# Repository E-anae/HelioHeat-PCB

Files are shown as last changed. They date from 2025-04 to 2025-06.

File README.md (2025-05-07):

# Projet ELEC - PCB

## Architecture

Cette section présente l'architecture d'un thermomètre autonome fonctionnant à
l'aide d'un panneau solaire. L'objectif est de mesurer la température d'un lieu
et d'afficher sur des afficheurs 7 segments tout en assurant une alimentation
énergétique durable à l'aide d'une batterie rechargeable.

### Composants principaux

Les composants que nous utiliserons sont les suivants :

| Référence | Composant | Quantité | Remarques |
| --- | --- | --- | ---- |
| ATTINY85 | Microcontrôleur | 1 | Gestion des capteurs et de l'affichage |
| MCP9700AT-E/LT | Capteur de température | 1 | Mesure de la température |
| 157119S12801 | Afficheur 7 segments | 3 | Affiche numérique de la température |
| PET Solar panel | Mini panneau solaire | 1 | Recharge la batterie |
| CD4511 | Décodeur BCD vers 7 segments | 3 | Simplifie le pilottage de l'afficheur |
| | Batterie rechargeable | 1 | Alimentation autonome |
| 74HC595 | Registre à décalage | 2 | Sérialisation des données |

### Schéma fonctionnel

1. Le panneau solaire charge la batterie via un circuit de gestion de charge.
2. La batterie alimente le microcontrôleur et les afficheurs 7 segments.
3. Le microcontrôleur lit la température via le capteur et affiche les valeurs
sur les afficheurs 7 segments.

Le schéma fonctionnel est présent dans le document `documents/schema.pdf`.

Ce projet permettra de développer une solution autonome et durable pour la
mesure de la température. La conception d'une carte PCB optimisera l'intégration
des composants et la gestion énergétique.

## Fonction de transfert du capteur de température

La fonction de transfert du capteur de température est explicitée dans la partie
4 (*Applications information*) de la fiche de donnée du capteur de température
(`documents/thermal_sensor_datasheet.pdf`).

Cette dernière nous informe que

$$
V_{OUT} = T_C \times T_A + V_{0°C}
$$

avec $V_{OUT}$ la tension de sortie du capteur, $T_C$ le coefficient de
température, $T_A$ la température ambiante et $V_{0°C}$ la tension de sortie du
capteur à 0°C.

On a alors,

$$
\begin{align*}
    V_{OUT} &= T_C \times T_A + V_{0°C} \\
    V_{OUT} - V_{0°C} &= T_C \times T_A \\
    T_A &= \frac{V_{OUT} - V_{0°C}}{T_C}
\end{align*}
$$

avec $V_{0°C} = 500 V$ et $T_C = 10.0 V$.

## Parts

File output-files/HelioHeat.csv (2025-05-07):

Reference | Value | Footprint | Datasheet | Qty | DNP | Exclude from BOM | Exclude from Board
D1,D2,D3 | WL-T7DS_0.39INCH_COMMON-ANODE | WL-T7DS_0.39INCH_COMMON-ANODE:WL-T7DS_0.39INCH |  | 3
J1 | USB_B_Micro | Connector_USB:USB_Micro-B_Amphenol_10103594-0001LF_Horizontal | ~ | 1
R1,R2,R3 | 220 | Resistor_SMD:R_0201_0603Metric | ~ | 3
U1 | ATtiny85-20P | Package_DIP:DIP-8_W7.62mm | http://ww1.microchip.com/downloads/en/DeviceDoc/atmel-2586-avr-8-bit-microcontroller-attiny25-attiny45-attiny85_datasheet.pdf | 1
U2,U3,U4 | CD4511BE | CD4511BE:DIP794W45P254L1969H508Q16 |  | 3
U5,U6 | 74HC595 | 74HC595:SO16 | http://www.ti.com/lit/ds/symlink/sn74hc595.pdf | 2
U7 | MCP9700Ax-ELT | Package_TO_SOT_SMD:SOT-353_SC-70-5 | http://ww1.microchip.com/downloads/en/DeviceDoc/20001942G.pdf | 1

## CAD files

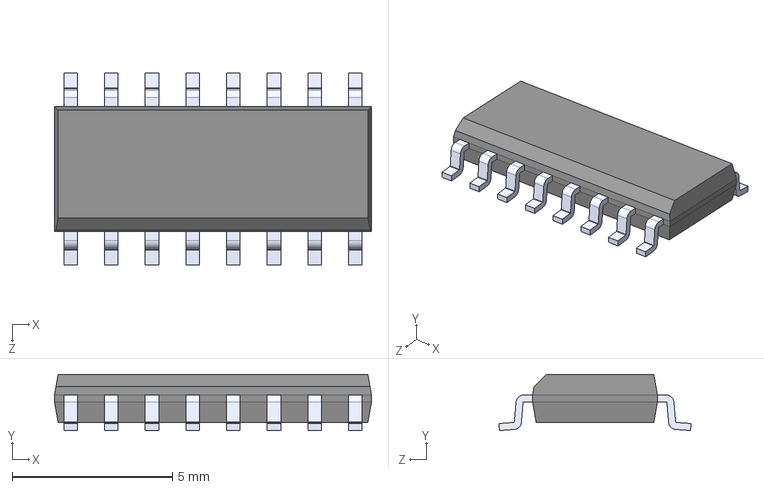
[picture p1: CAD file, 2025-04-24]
HelioHeatPartsLib/74HC595/74HC595.step
9.90 x 1.75 x 6.00 mm

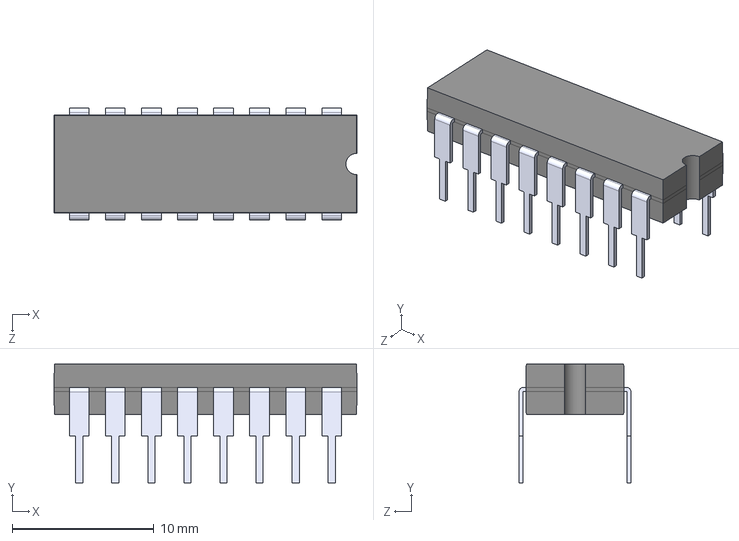
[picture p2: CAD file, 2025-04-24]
HelioHeatPartsLib/CD4511/CD4511BE.step
21.3 x 8.38 x 7.90 mm

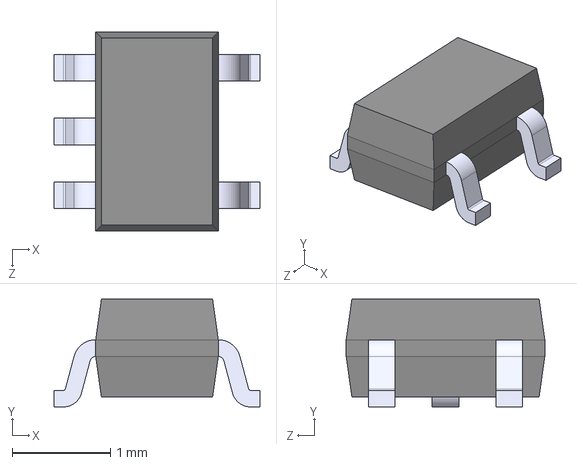
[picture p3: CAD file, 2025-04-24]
HelioHeatPartsLib/MCP9700AT-E_LT.step
2.10 x 1.10 x 2.02 mm

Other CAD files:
HelioHeatPartsLib/WL-T7DS 7 Segments Display THT Single Digit/WL-T7DS_0.39INCH_COMMON-ANODE.step

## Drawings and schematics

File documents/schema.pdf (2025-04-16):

A

1 | 2 | 3 | 4 | 5 | 6

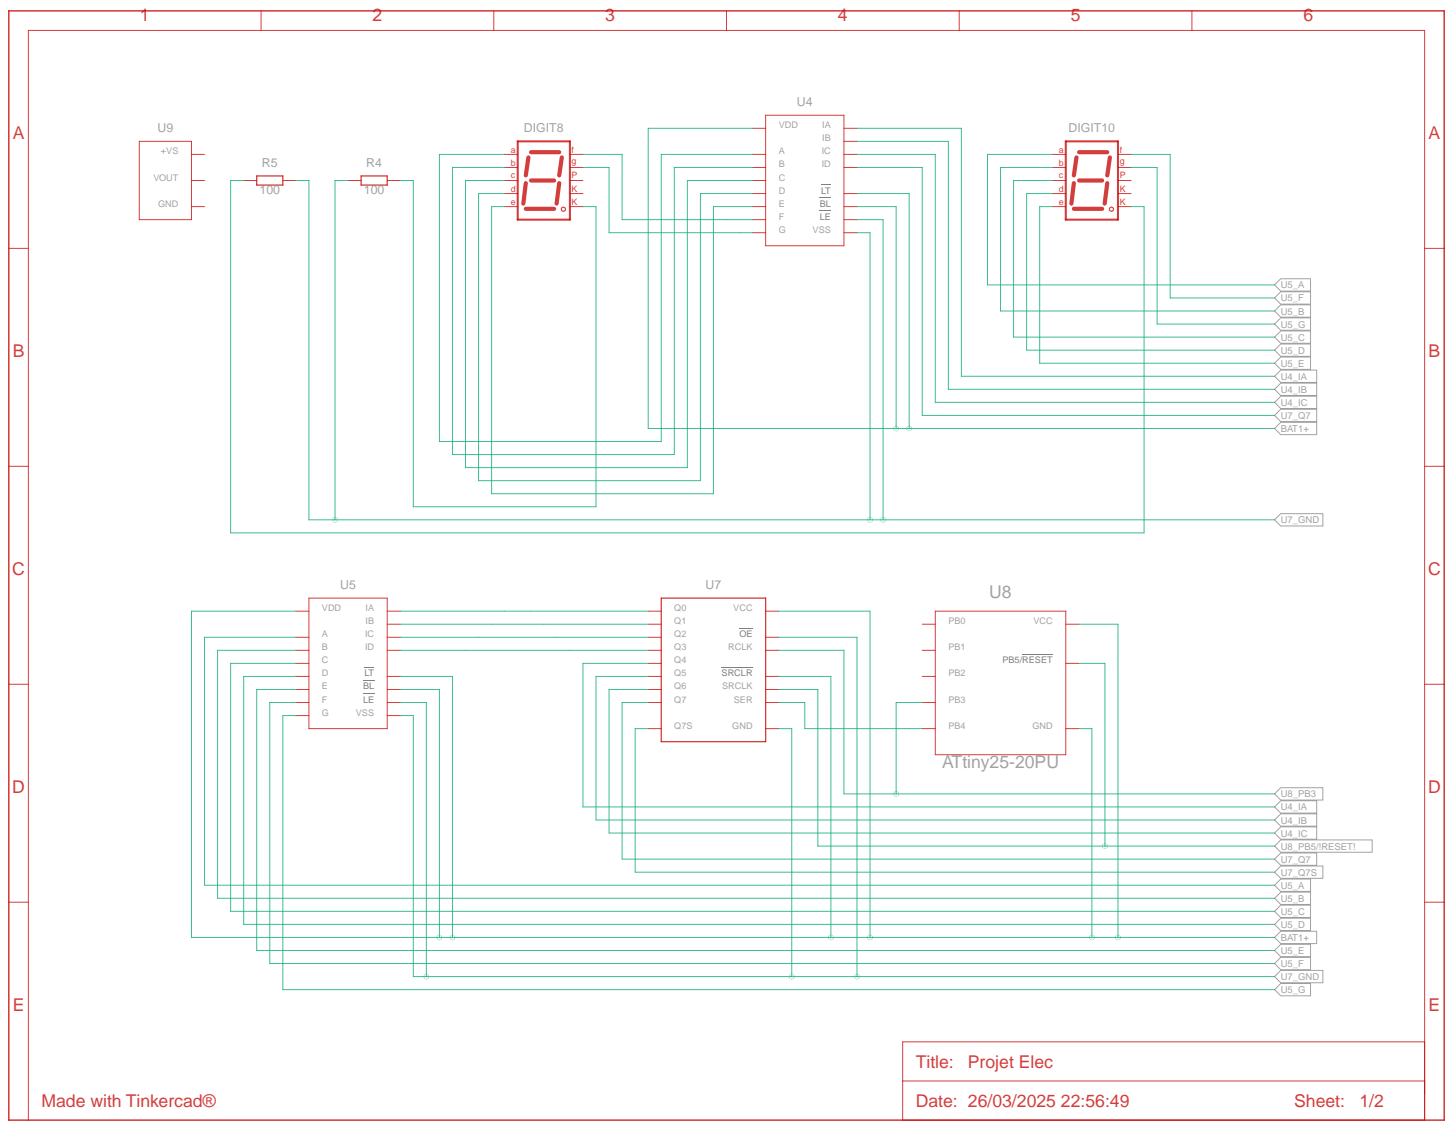
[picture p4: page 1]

A

1 | 2 | 3 | 4 | 5 | 6

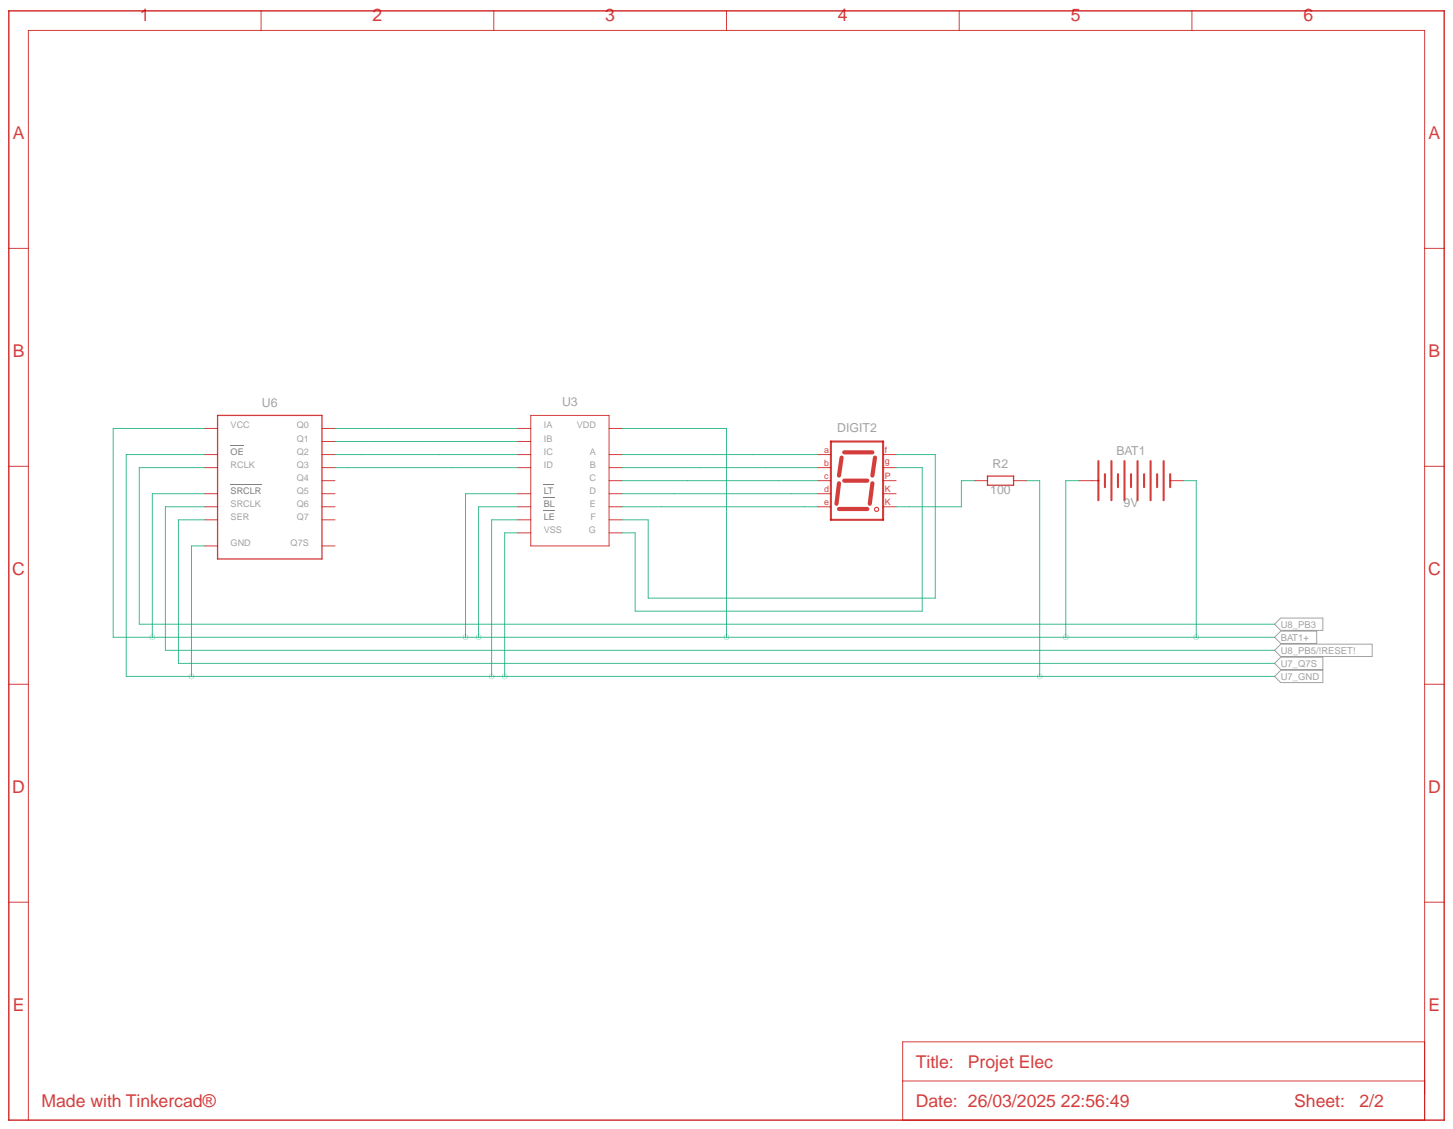
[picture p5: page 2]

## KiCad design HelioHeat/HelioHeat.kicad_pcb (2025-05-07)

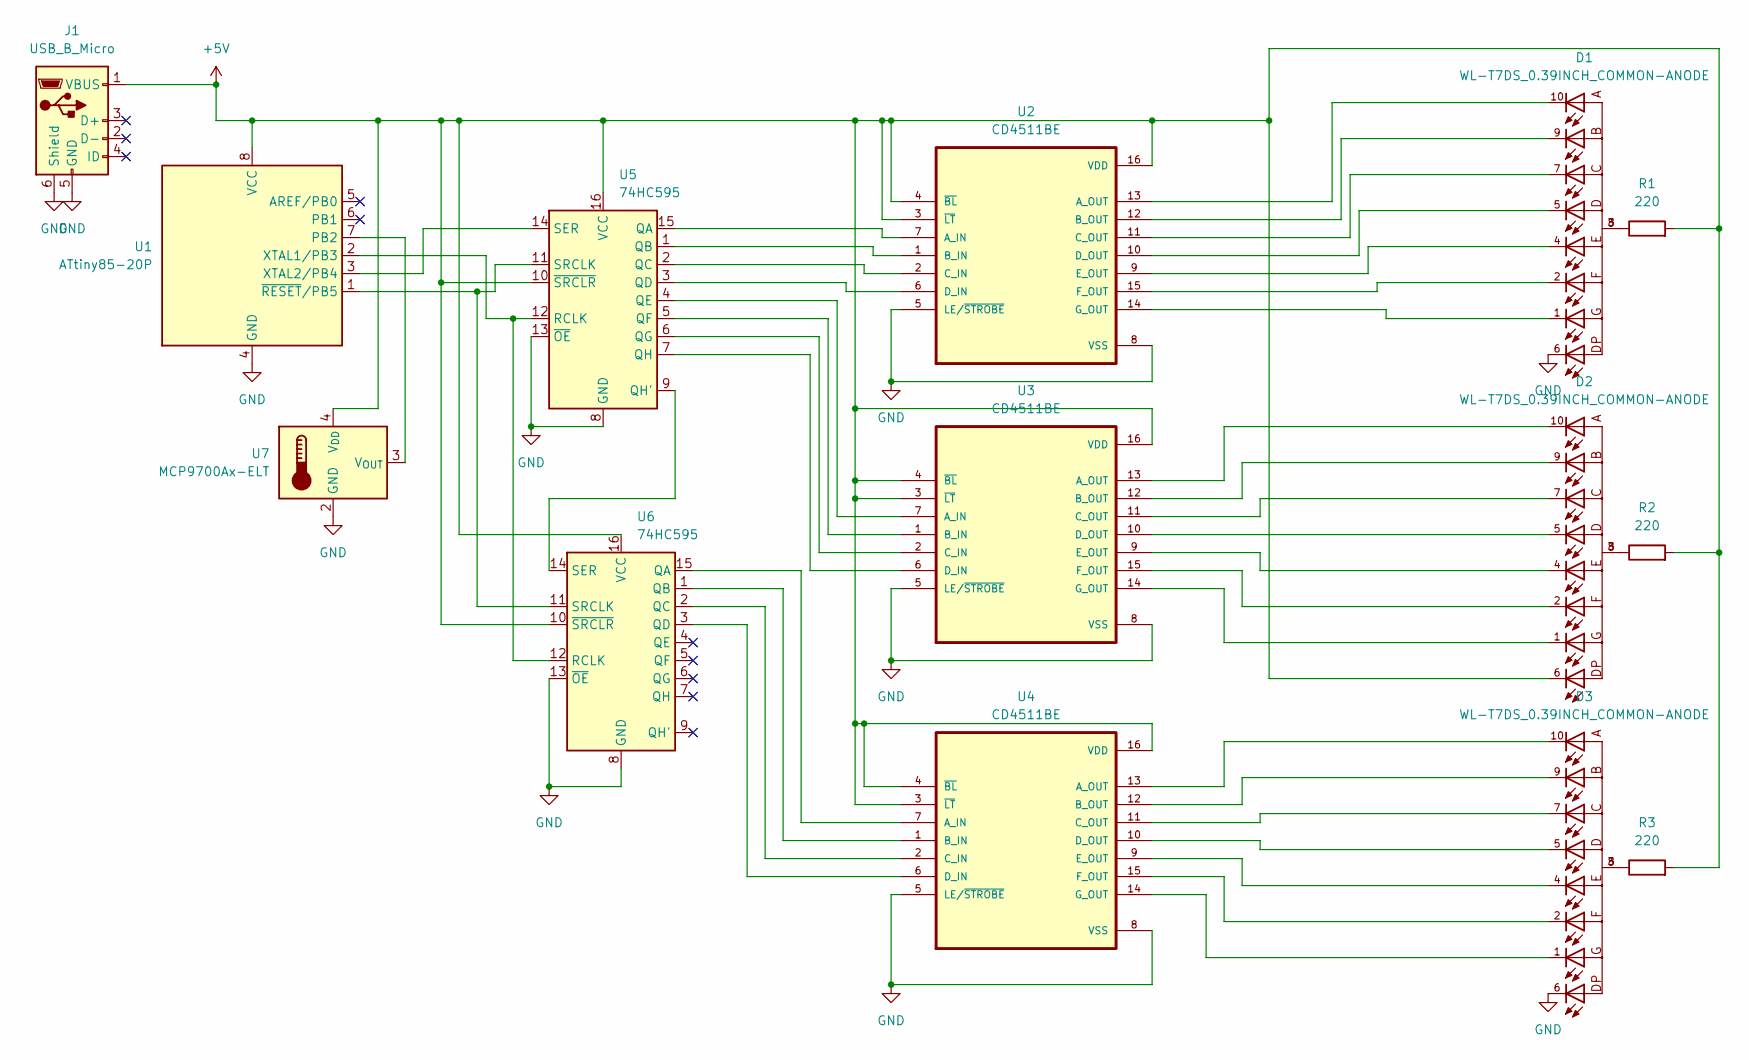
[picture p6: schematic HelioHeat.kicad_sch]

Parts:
D1, D2, D3: WL-T7DS_0.39INCH_COMMON-ANODE; WL-T7DS_0.39INCH
J1: USB_B_Micro; USB_Micro-B_Amphenol_10103594-0001LF_Horizontal
R1, R2, R3: 220; R_0201_0603Metric
U1: ATtiny85-20P; DIP-8_W7.62mm
U2, U3, U4: CD4511BE; DIP794W45P254L1969H508Q16
U5, U6: 74HC595; SO16
U7: MCP9700Ax-ELT; SOT-353_SC-70-5

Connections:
+5V: D2.6, J1.1 (VBUS), R1.2, R2.2, R3.2, U1.8 (VCC), U2.3 (~LT), U2.4 (~BL), U2.16 (VDD), U3.3 (~LT), U3.4 (~BL), U3.16 (VDD), U4.3 (~LT), U4.4 (~BL), U4.16 (VDD), U5.10 (~SRCLR), U5.16 (VCC), U6.10 (~SRCLR), U6.16 (VCC), U7.4 (V_{DD})
GND: D1.6, D3.6, J1.5 (GND), J1.6 (Shield), U1.4 (GND), U2.5 (LE/~STROBE), U2.8 (VSS), U3.5 (LE/~STROBE), U3.8 (VSS), U4.5 (LE/~STROBE), U4.8 (VSS), U5.8 (GND), U5.13 (~OE), U6.8 (GND), U6.13 (~OE), U7.2 (GND)
unnamed: D1.3, D1.8, R1.1
unnamed: D2.3, D2.8, R2.1
unnamed: D3.3, D3.8, R3.1
unnamed: U1.7 (PB2), U7.3 (V_{OUT})
unnamed: U1.2 (XTAL1/PB3), U5.12 (RCLK), U6.12 (RCLK)
unnamed: U1.3 (XTAL2/PB4), U5.14 (SER)
unnamed: U1.1 (~RESET/PB5), U5.11 (SRCLK), U6.11 (SRCLK)
unnamed: U2.7 (A_IN), U5.15 (QA)
unnamed: D1.10, U2.13 (A_OUT)
unnamed: U2.1 (B_IN), U5.1 (QB)
unnamed: D1.9, U2.12 (B_OUT)
unnamed: U2.2 (C_IN), U5.2 (QC)
unnamed: D1.7, U2.11 (C_OUT)
unnamed: U2.6 (D_IN), U5.3 (QD)
unnamed: D1.5, U2.10 (D_OUT)
unnamed: D1.4, U2.9 (E_OUT)
unnamed: D1.2, U2.15 (F_OUT)
unnamed: D1.1, U2.14 (G_OUT)
unnamed: U3.7 (A_IN), U5.4 (QE)
unnamed: D2.10, U3.13 (A_OUT)
unnamed: U3.1 (B_IN), U5.5 (QF)
unnamed: D2.9, U3.12 (B_OUT)
unnamed: U3.2 (C_IN), U5.6 (QG)
unnamed: D2.7, U3.11 (C_OUT)
unnamed: U3.6 (D_IN), U5.7 (QH)
unnamed: D2.5, U3.10 (D_OUT)
unnamed: D2.4, U3.9 (E_OUT)
unnamed: D2.2, U3.15 (F_OUT)
unnamed: D2.1, U3.14 (G_OUT)
unnamed: U4.7 (A_IN), U6.15 (QA)
unnamed: D3.10, U4.13 (A_OUT)
unnamed: U4.1 (B_IN), U6.1 (QB)
unnamed: D3.9, U4.12 (B_OUT)
unnamed: U4.2 (C_IN), U6.2 (QC)
unnamed: D3.7, U4.11 (C_OUT)
unnamed: U4.6 (D_IN), U6.3 (QD)
unnamed: D3.5, U4.10 (D_OUT)
unnamed: D3.4, U4.9 (E_OUT)
unnamed: D3.2, U4.15 (F_OUT)
unnamed: D3.1, U4.14 (G_OUT)
unnamed: U5.9 (QH'), U6.14 (SER)

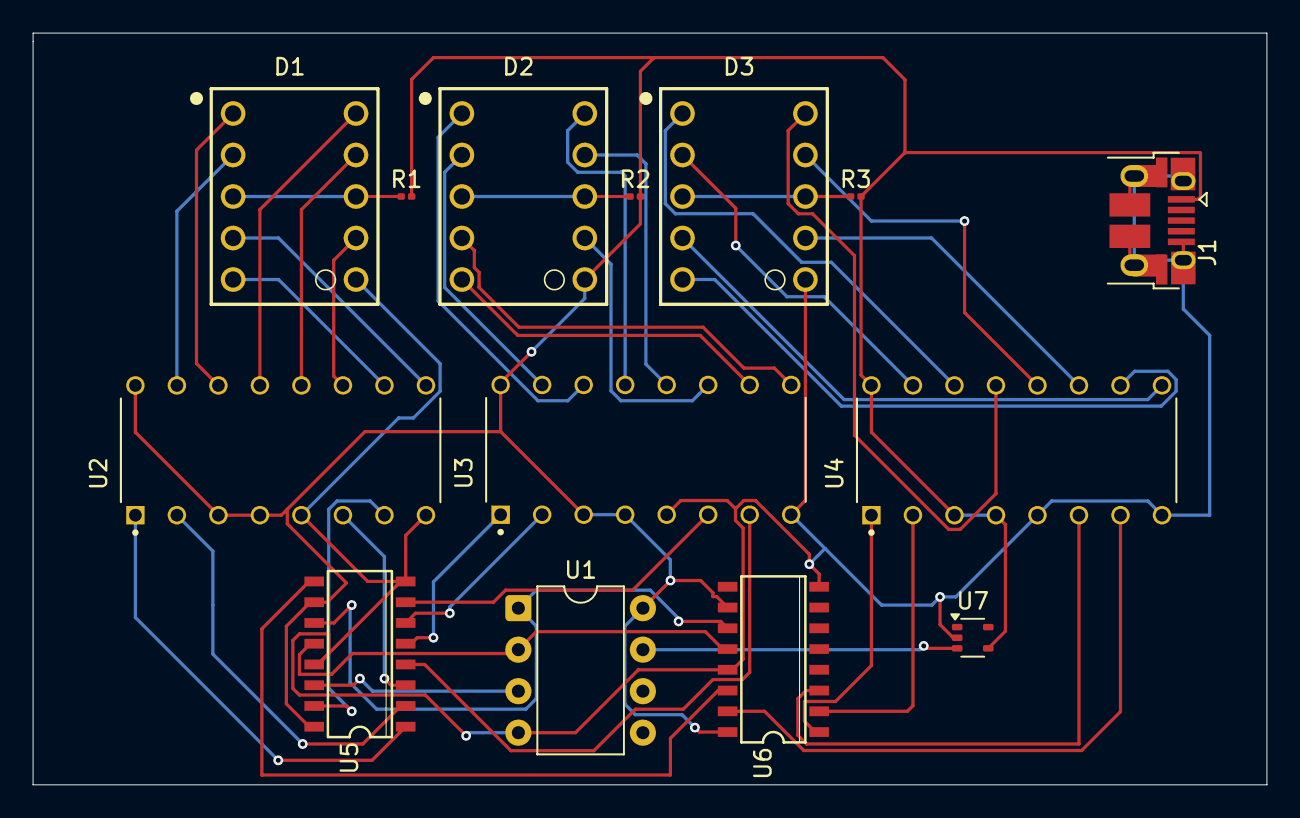
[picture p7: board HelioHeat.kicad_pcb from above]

Board: 2 copper layers, 75.5 x 46.0 mm, 14 parts (0 on the bottom side), 43 nets.

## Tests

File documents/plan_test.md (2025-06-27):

## Plan de Test pour le Projet HelioHeat

### Tests Électriques Passifs (avant alimentation)

Ces tests permettent de s'assurer que le circuit imprimé est correctement
réalisé et que les composants sont correctement soudés, sans alimenter le
circuit. Cela évite d'endommager les composants si une erreur matérielle est
présente.

#### Test de continuité

##### Objectif

Le but de ce test de continuité est de vérifier que toutes les pistes critiques
sont bien connectées selon le schéma électrique. Ce schéma électrique peut être
retrouvé dans les différents documents générés par *Kicad*.

##### Méthode

Pour les différents point, il nous faudra utiliser un multimètre en mode
continuité. On pourra alors tester :

* La connexion entre le pin Vcc de l'ATTiny et l’entrée Vcc du PCB.
* La masse commune (GND) sur tous les composants (ATTiny, capteur thermique,
  afficheurs, etc.).
* Les signaux de données (par ex. entre ATTiny et 74HC595).

#### Test d’isolement (absence de court-circuit)

##### Objectif

Dans le test d'isolement, il nous suffit de vérifier qu’il n’y a pas de
court-circuit involontaire, en particulier entre Vcc et GND.

##### Méthode

On pourra alors mesurer les différentes résistances entre Vcc et GND avec un
multimètre.

Si une valeur très basse (<10 Ω), elle sera alors suspecte.

#### Vérification de polarité des composants

##### Objectif

Pour vérifier la polarité des compostants, il nous faut vérifier l’orientation
correcte des composants polarisés.

##### Méthode

Visuellement, on peut vérifier les différents compostants avec leurs repères,
notamment sur l'AATTiny et les afficheurs 7 segments.

#### Vérification des soudures

##### Objectif

Nous pouvons également s’assurer que toutes les soudures sont propres et
fonctionnelles.

##### Méthode

À la loupe, nous pouvons vérifier qu'il n'ya pas de ponts de soudure, ni de
broches non soudées.

#### Vérification du brochage des connecteurs

##### Objectif

Le but de ces tests est de confirmer que les connecteurs sont câblés
conformément au schéma.

##### Méthode

En prenant le schéma PDF, généré par Kicad, on peut repérer chaque ligne de
signal. On peut alors vérifier que chaque broche correspond bien à la bonne
ligne (ex. : GND, VCC, DATA, CLK, etc.).

### Tests Fonctionnels (composant par composant)

Ces tests visent à vérifier que chaque composant du circuit fonctionne
indépendamment.

#### ATTiny

##### Objectif

Afin de tester l'ATTiny, on peut tester la programmation et le bon
fonctionnement du microcontrôleur.

##### Méthode

On peut flasher un code qui permettrait de faire clignoter une LED connectée à
une sortie.

#### Capteur thermique MCP9700AT

##### Objectif

Nous pouvons vérifier que la tension de sortie du capteur varie correctement
avec la température.

##### Méthode

En mesurant la sortie au multimètre du capteur de température, on peut soit
chauffer, soit refroidir lègèrement le capteur et vérifier les valeurs.

#### Registre à décalage

##### Objectif

Pour vérifier le registre à décalage, nous pouvons vérifier que les bits de
données sont correctement transférés.

##### Méthode

On peut utiliser une carte Arduino pour envoyer un signal série. On peut alors
observer les sorties avec un oscilloscope.

#### Décodage BCD vers 7 segments

##### Objectif

Cette partie a pour but de vérifier la conversion correcte de l’entrée BCD en
segments.

##### Méthode

En appliquant des valeurs de 0 à 9 sur les entrées, on peut vérifier
l'affichage sur les différents 7 segments présents sur le PCB.

#### Afficheur 7 segments

##### Objectif

Vérifier la lisibilité et la fonctionnalité des segments nous permettrait de
tester les différents afficheurs 7 segments.

##### Méthode

En alimentant directement chaque segment individuellement, on peut vérifier que
les segments s'allument clairement.

### Tests Système avec Firmware

#### Chargement du firmware

##### Objectif

On peut tester le code final (`main.ino`) pour tester le chargement du firmware.

##### Méthode

On peut utiliser *Arduino IDE*, on peut compiler et téléverser le firmware.

#### Affichage de température

##### Objectif

On peut alors vérifier que la température lue est affichée correctement.

##### Méthode

On peut alors comparer la température affichée avec un thermomètre réel.

#### Réactivité à la variation de température

##### Objectif

L'objectif est de s’assurer que le système réagit aux changements.

##### Méthode

Pour cela, on peut appliquer une variation thermique rapide, que ce soit en
chauffant ou refroidissant la carte.

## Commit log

2025-04-16 feat(documentation): add equation to find temperature
2025-04-24 feat: add missing pieces
    [74HC595.step, CD4511BE.step, HelioHeat.kicad_pcb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]
2025-05-06 quick adjusment
    [HelioHeat.kicad_pcb]
2025-05-07 i am a routeur
    [HelioHeat.kicad_pcb]
2025-05-07 feat: add output files
    [HelioHeat-B_Cu.gbr, HelioHeat-B_Mask.gbr, HelioHeat-B_Paste.gbr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]
